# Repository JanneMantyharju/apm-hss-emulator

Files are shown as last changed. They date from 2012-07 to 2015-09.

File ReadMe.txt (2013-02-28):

This repository contains sources for Ardupilot Mega to Hitec telemetry adapter
For more information see: http://wp.me/p12J9M-3M

Files in this repository:
adapter/ - Source files, compile with Arduino
libraries/ - Mavlink and support libraries
hss.sch - Schematics in Eagle format
hss.brd - Board in Eagle format

Compile to ATMega328p with 8MHz clock setting.

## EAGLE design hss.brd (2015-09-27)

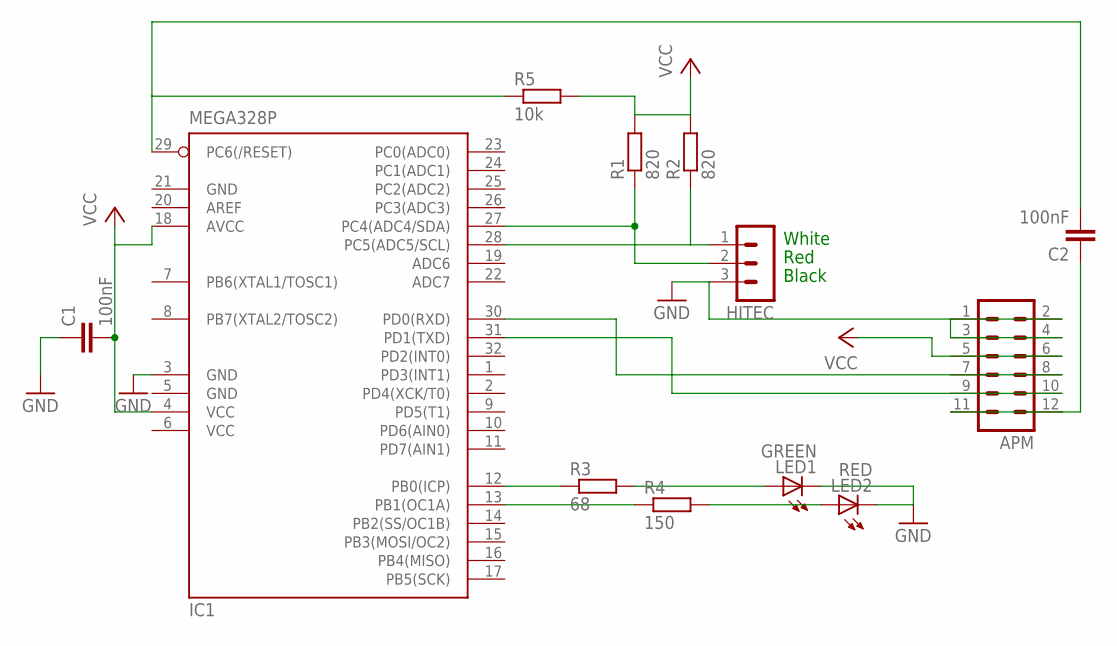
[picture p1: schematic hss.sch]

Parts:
APM: MA06-2
C1, C2: 100nF; C1206
HITEC: MA03-1
IC1: MEGA328P; TQFP32-08
LED1: GREEN; 1206
LED2: RED; 1206
R1, R2: 820; M1206
R3: 68; M1206
R4: 150; M1206
R5: 10k; M1206

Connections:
GND: APM.1, APM.2, APM.3, APM.4, C1.1, HITEC.3, IC1.3 (GND), IC1.5 (GND), IC1.21 (GND), LED1.C, LED2.C
unnamed: IC1.12 (PB0(ICP)), R3.1
unnamed: HITEC.2, IC1.27 (PC4(ADC4/SDA)), R1.1
unnamed: HITEC.1, IC1.28 (PC5(ADC5/SCL)), R2.1
unnamed: C2.2, IC1.29 (PC6(/RESET)), R5.1
unnamed: LED1.A, R3.2
unnamed: IC1.13 (PB1(OC1A)), R4.1
unnamed: LED2.A, R4.2
unnamed: APM.11, APM.12, C2.1
unnamed: APM.9, APM.10, IC1.31 (PD1(TXD))
unnamed: APM.7, APM.8, IC1.30 (PD0(RXD))
VCC: APM.5, APM.6, C1.2, IC1.4 (VCC), IC1.6 (VCC), IC1.18 (AVCC), R1.2, R2.2, R5.2

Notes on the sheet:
White
Red
Black

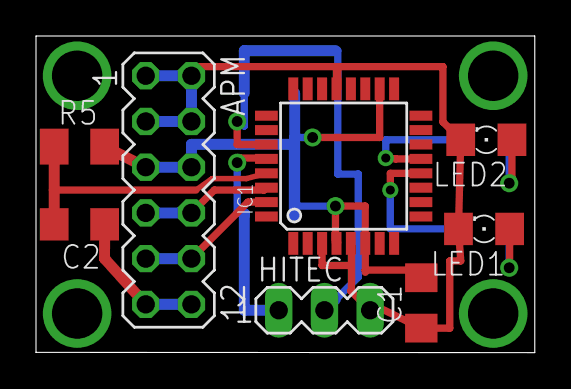
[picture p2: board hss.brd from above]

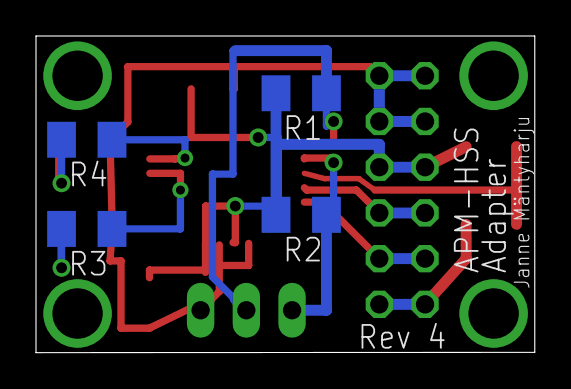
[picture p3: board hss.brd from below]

Board: 2 copper layers, 27.7 x 17.6 mm, 12 parts (4 on the bottom side), 12 nets.

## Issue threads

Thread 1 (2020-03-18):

connections to program

RawLiquid, 2020-03-18:
Is it just me, or is there no way to program the chip while it is on the board?

RawLiquid, 2020-03-18:
Nevermind, I think I  had a brain fart...Only needs serial access to reprogram as long as the chip already has the bootloader... I was thinking the ICSP header was required...

JanneMantyharju, 2020-03-19:
Yes, I have test socket for avr chips, which I use to burn the bootloader in them before soldering the chip to the board.

Closed 2020-03-18.

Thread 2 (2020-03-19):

Unable to build

RawLiquid, 2020-03-19:
Hey, is so the libraries you provide call for AP_MATH, which isn't included, I've tried supplying the things it wants but that didn't help any....

JanneMantyharju, 2020-03-19:
Thanks for reminding me about this project :-D AP_MATH comes from APM source, so you need to have it's libraries on your library path. If you get errors while compiling, try to use APM source from about the time when apm-hss-emulator source is dated. It might be that the current version is not compatible any more.

Closed 2020-03-19.

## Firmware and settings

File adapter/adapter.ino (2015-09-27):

/*
 * Code by Janne Mäntyharju
 * Author note for HSS emulation part: Author Kim Mattsson, base from  Kroeske
 * MavLink code borrowed from MinimOsd project
 *
 * NB! If using Atmega168, change MAVLINK_MAX_PAYLOAD_LEN to 35 in include/mavlink/v1.0/mavlink_types.h
 * Display setup:
 * RPM 1: Distance to home
 * RPM 2: Airspeed
 * TEMP 1: Battery remaining percentage
 * TEMP 2: Throttle position
 * TEMP 3: Variometer
 * TEMP 4: Armed status (1 = Armed)
 */

#include <FastSerial.h>
#include "Wire.h"
#include <GCS_MAVLink.h>
#include <SimpleTimer.h>
#include <DigitalToggle.h>

#define Hitec_i2c  0x08         // Hitec Telemetry module address
#define TELEMETRY_SPEED  57600  // How fast our MAVLink telemetry is coming to Serial port
#define SPEKTRUM_MESSAGES 4
#define HITEC_MESSAGES 8
#define HITEC 0
#define SPEKTRUM 1
#define LED_GREEN 8
#define LED_RED 9

FastSerialPort0(Serial);

SimpleTimer  mavTimer;
SimpleTimer  homeTimer;

static uint8_t      got_home = 0;
static uint8_t      fix_type = 0;
static float        lat = 0;                    // latidude
static float        lon = 0;                    // longitude
static float        home_lat = 0;               // home latidude
static float        home_lon = 0;               // home longitude
static float        home_alt = 0;
static uint8_t      alt_cnt = 0;
static float        alt_prev = 0;             // previous altitude
static float        alt = 0;
static float        climb = 0.0;
static float        alpha = 0.8;                // value for exponential moving average

static uint8_t msgId = 0;
static uint8_t telemetry_type = HITEC;

byte data_spektrum[SPEKTRUM_MESSAGES][16] = {
  {0x03, 00, 00, 50, 0x00, 0x00, 00, 00, 00, 00, 00, 00, 00, 00, 00, 00},   // 2-3 Current, unsigned 1 unit is 0.1967A
  {0x0a, 00, 00, 50, 0x00, 0x00, 00, 00, 00, 00, 00, 00, 00, 00, 00, 00}, // 2-3 Volts, unsigned 1 unit is 0.01v, 6-7 capacity, unsigned 1 unit is 1mAh
  {0x11, 00, 00, 50, 0x01, 0xF9, 00, 00, 00, 00, 00, 00, 00, 00, 00, 00}, // 2-3 airspeed unsigned 1 unit is 1 km/h
  {0x12, 00, 00, 50, 0xFF, 0x00, 00, 00, 00, 00, 00, 00, 00, 00, 00, 00} // 2-3 altitude, signed 1 unit is 0.1 m
};

byte data_hss[HITEC_MESSAGES][7] = { 
  {0x11, 0xAF, 0x00, 0x2D, 0x00, 0x00, 0x11}, // 1 Frametype, 4&5 Internal  SPC voltage
  {0x12, 0x00, 0x2C, 0x2C, 0x2E, 0x25, 0x12},     // 1-4 Latitude 5=gps sec,
  {0x13, 0x18, 0x01, 0xD4, 0x22, 0x28, 0x13},     // 1-4 Longitude, 5 = TEMP2
  {0x14, 0x00, 0x00, 0x00, 0x00, 0x28, 0x14},     //1&2=Speed,,3&4 = altitude,5= Temp1
  {0x15, 0x03, 0xFF, 0x01, 0xFE, 0x01, 0x15},     // 1 = Fuelgauge, 2&3 RPM1, 4&5 RPM2
  {0x16, 0x3C, 0x04, 0x1D, 0x00, 0x00, 0x16},     // 1= year,m,date, h, min 
  {0x17, 0x00, 0x99, 0x06, 0x28, 0x28, 0x17},     // 3= GPS Signal 4=Temp3, 5=Temp4
  {0x18, 0x00, 0x00, 0x00, 0x00, 0x00, 0x18}      // 1&2 Voltage
};                              

void Send_Data()
{
  digitalToggle(LED_RED);
  if(telemetry_type == HITEC) {
    Wire.write(data_hss[msgId], 7);
    msgId++;
    msgId %= HITEC_MESSAGES;
  } else {
    Wire.write(data_spektrum[msgId], 16);
    msgId++;
    msgId %= SPEKTRUM_MESSAGES;
  }
}

// Works  , nr is channel, and value is rpm
void setRpm(int nr, unsigned int value)
{
    unsigned char rpml = (value / 10) % 0x100;
    unsigned char rpmh = (value / 10) / 0x100;

    switch (nr) {
        case 1:
            data_hss[4][2] = rpml;
            data_hss[4][3] = rpmh;
            break;

        case 2:
            data_hss[4][4] = rpml;
            data_hss[4][5] = rpmh;
            break;

        default:
            break;
    }
}

/*
 *  Valuerange 0-4
 */
void FuelGauge(unsigned char value)
{
    if (value > 4)
        data_hss[4][1] = 4;
    else
        data_hss[4][1] = value;
}

//works, Range is -40 - +215c
void setTemp(int nr, char value)
{
  value+=40;
    switch (nr) {
        case 1:
            data_hss[3][5] = value;
            break;

        case 2:
            data_hss[2][5] = value;
            break;

        case 3:
            data_hss[6][4] = value;
            break;

        case 4:
            data_hss[6][5] = value;

        default:
            break;
    }
}

//  Works Values 0-500km/h
void setSpeed(unsigned int value)
{
  if(telemetry_type == HITEC) {
    if (value <= 500) {
        data_hss[3][2] = value % 0x100;
        data_hss[3][1] = value / 0x100;
    }
  } else {
    data_spektrum[2][2] = value % 0x100;
    data_spektrum[2][3] = value / 0x100;
  }
}

// Value in meters 
void setAltitude(unsigned int value)
{
  if(telemetry_type == HITEC) {
    if (value < 9999) {
        data_hss[3][4] = value % 0x100;
        data_hss[3][3] = value / 0x100;
    }
  } else {
    value *= 10;
    data_spektrum[3][2] = value % 0x100;
    data_spektrum[3][3] = value / 0x100;
  }
}

// Value is 6-1002, Value is 0.1 volt), minimum measurement is 6 that equals to 0.6v
void setVoltage(unsigned int value)
{
  if(telemetry_type == HITEC) {
    if ((value > 6) & (value < 1001)) {
        data_hss[7][1] = (value - 2) % 0x100;;      // % 0x100;
        data_hss[7][2] = value / 0x100;
    }
  } else {
    value *= 0.1;
    data_spektrum[1][2] = value % 0x100;
    data_spektrum[1][3] = value / 0x100;
  }
}

 // value  1 = 0.1A, presented function is close enough, more accurate with float, but don't want to include the huge library
void setAmpere(unsigned int value)
{
  uint32_t t = 0;
  uint16_t v;

  if(telemetry_type == HITEC) {
    if (value) {
        t = (value - 1);
        t = t * 1435;
        t = t / 1000;
    }
    v = (uint16_t) (t) + 167;
    data_hss[7][3] = v % 0x100;;    // % 0x100;
    data_hss[7][4] = v / 0x100;
  } else {
    value *= 10;
    value /= 0.1967;
    data_spektrum[0][2] = value % 0x100;
    data_spektrum[0][3] = value / 0x100;
  }
}

/*
 * longitude and latitude are in GPS decimal, Aurora shows deg.min.sec
 * format is ddmm ss(,)ss
 */
void convertCoords(long *from, int *dm, int *s)
{
    int x;
    
    *dm = *from / 10000000;    
    *from -= *dm * 10000000;
    *from *= 6;
    x = *from / 1000000;
    *dm *= 100;
    *dm += x;
    
    *from -= x * 1000000;
    *s = *from / 100;
}

void setGPSLon(long longitude)
{
    int dm;
    int s;
    
    convertCoords(&longitude, &dm, &s);
    
    data_hss[2][2] = s & 0xff;
    data_hss[2][1] = s >> 8;

    data_hss[2][4] = dm & 0xff;
    data_hss[2][3] = dm >> 8;
}

void setGPSLat(long latitude)
{
    int dm;
    int s;
    
    convertCoords(&latitude, &dm, &s);
        
    data_hss[1][2] = s & 0xff;
    data_hss[1][1] = s >> 8;

    data_hss[1][4] = dm & 0xff;
    data_hss[1][3] = dm >> 8;
}

//Works, shows the signal strength, one bar /satelite, limit to 5
void setGPSSignal(char c)
{
    data_hss[6][3] = c;
}

void setup()
{
    Serial.begin(TELEMETRY_SPEED);
    // setup mavlink port
    mavlink_comm_0_port = &Serial;
    Wire.begin(Hitec_i2c);
    Wire.onRequest(Send_Data);
    if(telemetry_type == SPEKTRUM)
      TWAMR = 0xff; // respond to any request
    
    homeTimer.Set(&setHomeVars, 120);
    homeTimer.Enable();
    mavTimer.Set(&request_mavlink_rates, 1000);
    mavTimer.Enable();

    pinMode(LED_GREEN, OUTPUT);
    pinMode(LED_RED, OUTPUT);
    digitalWrite(LED_GREEN, HIGH);
    digitalWrite(LED_RED, HIGH);
    delay(1000);
    digitalWrite(LED_GREEN, LOW);
    digitalWrite(LED_RED, LOW);    
}

void setHomeVars()
{
    float dstlon, dstlat;
 
    if(got_home == 0 && fix_type > 1) {
        if(alt_cnt < 25) {
            if(fabs(alt_prev - alt) > 0.5) {
                alt_cnt = 0;
                alt_prev = alt;
            } else {
                if(++alt_cnt >= 25) {
                    home_alt = alt;
                    home_lat = lat;
                    home_lon = lon;
                    got_home = 1;
                }
            }
        }
    } else if(got_home == 1) {
        // shrinking factor for longitude going to poles direction
        float rads = fabs(home_lat) * 0.0174532925;
        double scaleLongDown = cos(rads);

        //DST to Home
        dstlat = fabs(home_lat - lat) * 111319.5;
        dstlon = fabs(home_lon - lon) * 111319.5 * scaleLongDown;
        setRpm(1, sqrt(sq(dstlat) + sq(dstlon)));
    }
}

void loop()
{
    read_mavlink();
    mavTimer.Run();
    homeTimer.Run();
}

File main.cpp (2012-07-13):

/*
 * Author note for HSS emulation part: Author Kim Mattsson, base from  Kroeske
 * 
 * GPS position and time functions are currently commented out. I'll rewrite them later.
 * Serial messages are only for debugging and can be removed.
 * 
 * Code by Janne Mäntyharju
 */


#include "WProgram.h"

#include <Wire/Wire.h>

#define Hitec_i2c  0x08         // Hitec Telemetry module address
//#define USE_SPI

typedef union {
        long l;
	float f;
        int i;
        unsigned int ui;
        unsigned char uc;
        byte buf[4];
} UNI;

byte state = 0;
UNI u;

void handle_byte(byte);

enum hss_states {
	hss_temp = 0,
	hss_voltage,
	hss_amps,
	hss_current_total,
	hss_battery_remaining,
	hss_alt,
	hss_groundspeed,
	hss_num_satellites,
	hss_airspeed,
	hss_throttle,
    hss_longitude,
    hss_latitude,
	hss_end
};

char data[8][7] = { {0x11, 0xAF, 0x00, 0x2D, 0x00, 0x00, 0x11}, // 1 Frametype, 4&5 Internal  SPC voltage
{0x12, 0x00, 0x2C, 0x2C, 0x2E, 0x25, 0x12},     // 1-4 Latitude 5=gps sec,
{0x13, 0x18, 0x01, 0xD4, 0x22, 0x28, 0x13},     // 1-4 Longitude, 5 = TEMP2
{0x14, 0x00, 0x00, 0x00, 0x00, 0x28, 0x14},     //1&2=Speed,,3&4 = altitude,5= Temp1
{0x15, 0x00, 0xFF, 0x01, 0xFE, 0x01, 0x15},     // 1 = Fuelgauge, 2&3 RPM1, 4&5 RPM2
{0x16, 0x3C, 0x04, 0x1D, 0x00, 0x00, 0x16},     // 1= year,m,date, h, min 
{0x17, 0x00, 0x99, 0x06, 0x28, 0x28, 0x17},     // 3= GPS Signal 4=Temp3, 5=Temp4
{0x18, 0x00, 0x00, 0x00, 0x00, 0x00, 0x18}
};                              // 1&2 Voltage

extern "C" void __cxa_pure_virtual()
 {
     cli();    // disable interrupts
     for(;;);  // do nothing until hard reset
}

void Send_Hitec()
{
    static unsigned char msgId = 0;

    if (TWAR != (Hitec_i2c << 1))
        return;                 //check if Hitecs telemetry address, someone else could be sending also through IRQ. 

    // We need to send only one Idrow/request, because of receiver  "odd" handshaking that Wire lib not support (TWEA after every row)
    Wire.send((uint8_t *) data + msgId * 7, 7);
    msgId++;
    msgId %= 8;
}

// Works  , nr is channel, and value is rpm
void setRpm(int nr, unsigned int value)
{
    unsigned char rpml = (value / 10) % 0x100;
    unsigned char rpmh = (value / 10) / 0x100;

    switch (nr) {
        case 1:
            data[4][2] = rpml;
            data[4][3] = rpmh;
            break;

        case 2:
            data[4][4] = rpml;
            data[4][5] = rpmh;
            break;

        default:
            break;
    }
}

/*
 *  Valuerange 0-4
 */
void FuelGauge(unsigned char value)
{
    if (value > 4)
        data[4][1] = 4;
    else
        data[4][1] = value;
}

//works, Values are 0-255, value 0 is -40C 255 =215C
void setTemp(int nr, unsigned char value)
{
    switch (nr) {
        case 1:
            data[3][5] = value;
            break;

        case 2:
            data[2][5] = value;
            break;

        case 3:
            data[6][4] = value;
            break;

        case 4:
            data[6][5] = value;

        default:
            break;
    }
}

//  Works Values 0-500km/h
void setSpeed(unsigned int value)
{
    if (value <= 500) {
        data[3][2] = value % 0x100;
        data[3][1] = value / 0x100;
    }
}

// Value in meters 
void setAltitude(unsigned int value)
{
    if (value < 9999) {
        data[3][4] = value % 0x100;
        data[3][3] = value / 0x100;
    }
}

// Value is 6-1002, Value is 0.1 volt), minimum measurement is 6 that equals to 0.6v
void setVoltage(unsigned int value)
{
    if ((value > 6) & (value < 1001)) {
        data[7][1] = (value - 2) % 0x100;;      // % 0x100;
        data[7][2] = value / 0x100;
    }
}

 // value  1 = 0.1mA, presented function is close enough, more accurate with float, but don't want to include the huge library
void setAmpere(unsigned int value)
{
    uint32_t t = 0;

    uint16_t v;

    if (value) {
        t = (value - 1);
        t = t * 1435;
        t = t / 1000;
    }
    v = (uint16_t) (t) + 167;
    data[7][3] = v % 0x100;;    // % 0x100;
    data[7][4] = v / 0x100;
}

/*
 * longitude and latitude are in GPS decimal, Aurora shows deg.min.sec
 * format is ddmm ss(,)ss
 */
void convertCoords(long *from, int *dm, int *s)
{
	int x;
	
	*dm = *from / 10000000;    
	*from -= *dm * 10000000;
	*from *= 6;
	x = *from / 1000000;
	*dm *= 100;
	*dm += x;
	
	*from -= x * 1000000;
	*s = *from / 100;
}

void setGPSLon(long longitude)
{
    int dm;
    int s;
    
    convertCoords(&longitude, &dm, &s);
    
    data[2][2] = s & 0xff;
    data[2][1] = s >> 8;

    data[2][4] = dm & 0xff;
    data[2][3] = dm >> 8;
}

void setGPSLat(long latitude)
{
	int dm;
	int s;
	
	convertCoords(&latitude, &dm, &s);
	    
    data[1][2] = s & 0xff;
    data[1][1] = s >> 8;

    data[1][4] = dm & 0xff;
    data[1][3] = dm >> 8;
}

// reguires date in format yymmdd as a long
/*void setGPSDate(long t)
{
    char x[15];
    
    sprintf(x, "%06.6lu", t);
    data[5][1] = (x[0] - 48) * 10 + x[1] - 48;  //yy
    data[5][2] = (x[2] - 48) * 10 + x[3] - 48;  //mm
    data[5][3] = (x[4] - 48) * 10 + x[5] - 48;  //dd
}*/



// Works, Time in t, format hhmmssmss
/*
void setGPSTime(long t)
{

    char x[15];

    sprintf(x, "%09.9lu", t);
    data[5][4] = (x[0] - 48) * 10 + x[1] - 48;
    data[5][5] = (x[2] - 48) * 10 + x[3] - 48;
    data[1][5] = (x[4] - 48) * 10 + x[5] - 48;
}*/



//Works, shows the signal strength, one bar /satelite, limit to 5
void setGPSSignal(char c)
{
    data[6][3] = c;
}

void setup()
{
    Serial.begin(38400);
#ifdef USE_SPI
    SPCR = _BV(SPE) | _BV(CPOL) | _BV(CPHA); // Enable SPI, Mode 3
#endif
    Wire.begin(Hitec_i2c);
    Wire.onRequest(Send_Hitec);
    DDRB = _BV(DDB0);
}

byte get_data()
{
	byte i;
	byte last_char = 0;
	byte c;
	
	for(i = 0; i < 4; i++) {
#ifdef USE_SPI
        loop_until_bit_is_set(SPSR, SPIF);
        c = SPDR;
#else
		while (!Serial.available());
		c = Serial.read();
#endif
		if (last_char == '*' && c == '*')
			return 0;
		u.buf[i] = c;
		last_char = c;
	}
	
	return 1;
}
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

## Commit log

2012-05-10 Support for APM2 GPS coordinates are now also shown
    [hss.sch]
2012-07-13 Ported patch to work with APM version 2.40. Fixed voltage display Added ability to start the video transmitter only after gps lock has been achieved
    [hss.pde, main.cpp]
2012-09-21 * Updated patch to work with APM 2.63 * Updated makefile and source to compile with Arduino 1.0
2013-02-28 Third iteration of APM adapter
    [hss.brd, hss.sch]
2013-03-25 Corrected schematic & board
    [hss.brd, hss.sch]
2013-04-04 * Phanged throttle to rpm 2 and airspeed to temp 2 * Added rolling average filter to vario (climb) reading * Home altitude is now substracted from gps altitude
2015-08-31 I2C improvement
2015-09-27 version 4 of the board
    [hss.brd, hss.sch]
